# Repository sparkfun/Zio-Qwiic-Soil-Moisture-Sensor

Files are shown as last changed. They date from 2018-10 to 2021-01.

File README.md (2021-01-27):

SparkFun Qwiic Soil Moisture Sensor
========================================

SparkFun Qwiic Soil Moisture Sensor

[*SparkFun Qwiic Soil Moisture Sensor (17731)*](https://www.sparkfun.com/products/17731)

The SparkFun Qwiic Soil Moisture Sensor is a simple breakout for measuring the moisture in soil and similar materials. The soil moisture sensor is pretty straightforward to use. The two large, exposed pads function as probes for the sensor, together acting as a variable resistor. The more water that is in the soil means the better the conductivity between the pads will be, resulting in a lower resistance and a higher SIG out. This version of the Soil Moisture Sensor includes a Qwiic connector, making it even easier to use this sensor!

To get the SparkFun Soil Moisture Sensor functioning, all you will need is to connect the VCC and GND pins to your Arduino-based device (or compatible development board). You will receive a SIG out, which will depend on the amount of water in the soil. One commonly known issue with soil moisture senors is their short lifespan when exposed to a moist environment. To combat this, we’ve had the PCB coated in gold finishing (ENIG, or Electroless Nickel Immersion Gold).

Built in cooperation with [Zio Smart Prototyping](https://www.smart-prototyping.com/Zio/Zio-Qwiic-Soil-Moisture-Sensor)! 

#### Specification

* I2C address: 0x07- 0x78 (Default: 0x28)
* Gateway MCU: ATtiny85-20SU
* Probes Surface Finish: Gold Immersion
* Weight: 6.0g
* Module dimension: 20.3x 100.0mm

Documentation
--------------
* **[Hookup Guide](https://learn.sparkfun.com/tutorials/soil-moisture-sensor-hookup-guide)** - Basic hookup guide for the SparkFun Qwiic Soil Moisture Sensor.
* [ATtiny85 Gateway Firmware](https://github.com/ZIOCC/Zio-Qwiic-Soil-Moisture-Sensor/tree/master/Firmware/Qwiic_Soil_Moisture_Sensor_Gateway_Firmware/Qwiic_Soil_Moisture_Firmware)

License Information
-------------------

This product is _**open source**_! 

Please review the LICENSE.md file for license information. 

If you have any questions or concerns on licensing, please contact technical support on our [SparkFun forums](https://forum.sparkfun.com/viewforum.php?f=152).

Distributed as-is; no warranty is given.

- Your friends at SparkFun.

_<COLLABORATION CREDIT>_

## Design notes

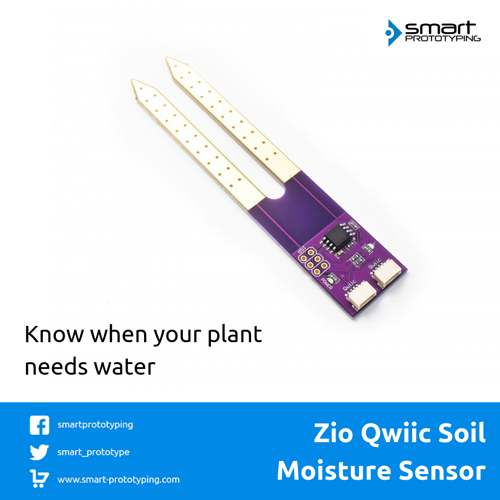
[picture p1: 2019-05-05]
soil-moisture.png

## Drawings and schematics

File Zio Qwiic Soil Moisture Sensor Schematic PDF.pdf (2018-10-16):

1 | 2 | 3 | 4

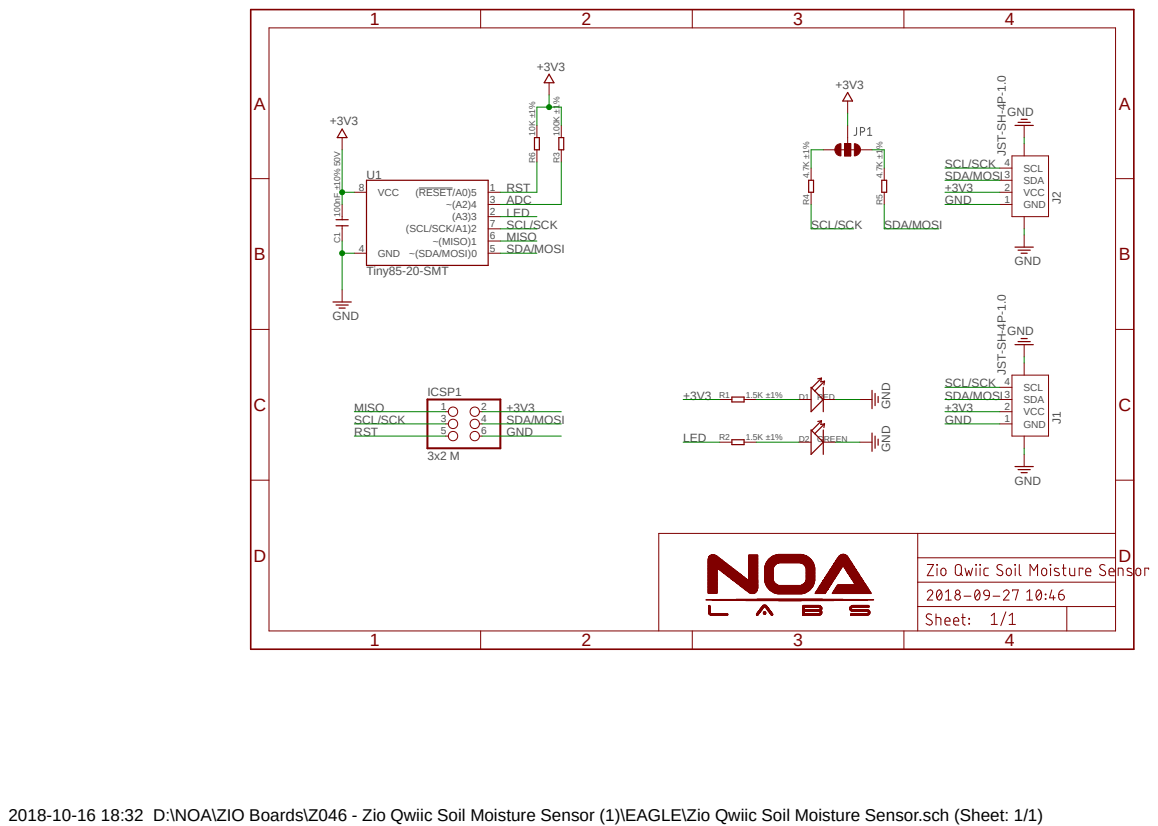
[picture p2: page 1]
Tiny85-20-SMT; GND¹⁰⁰nF ±10% ⁵⁰V; GND; GND 4.7K ±1%; RED; GREEN; GND GND ¹⁰⁰K ±1%; GND ¹⁰K ±1%; U1 VCC 8; ~(MISO)1; (RESET/A0)5; GND 4; ~(SDA/MOSI)0; (SCL/SCK/A1)2; GND 1; VCC 2; SDA 3; SCL 4; J2 JST⁻SH⁻⁴P⁻¹.0 R⁴; ICSP1 1 2 3 4 5 6; J1 JST⁻SH⁻⁴P⁻¹.0 R⁶; LED; ADC; RST; SDA/MOSI; SCL/SCK; MISO

2018-10-16 18:32 D:\NOA\ZIO Boards\Z046 - Zio Qwiic Soil Moisture Sensor (1)\EAGLE\Zio Qwiic Soil Moisture Sensor.sch (Sheet: 1/1)

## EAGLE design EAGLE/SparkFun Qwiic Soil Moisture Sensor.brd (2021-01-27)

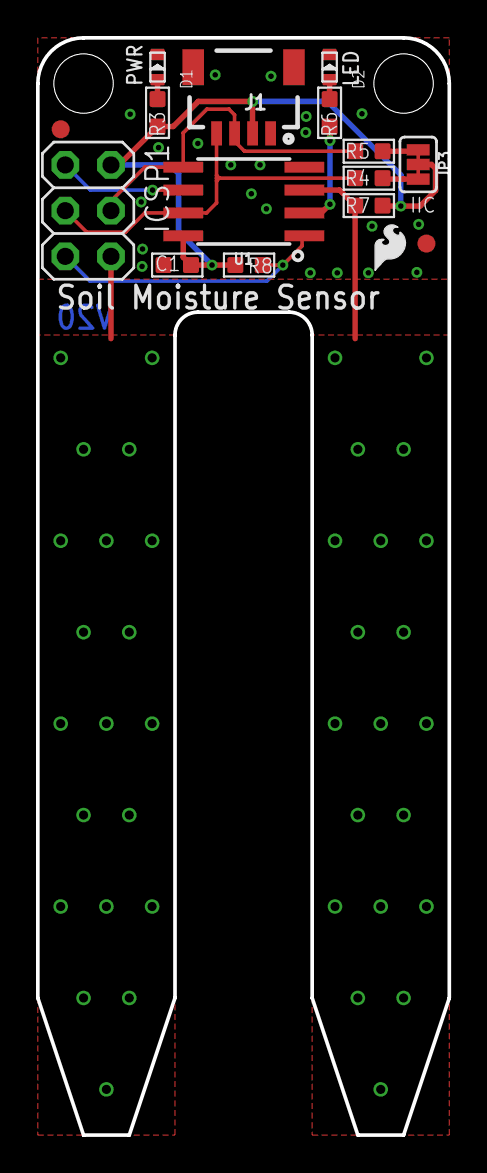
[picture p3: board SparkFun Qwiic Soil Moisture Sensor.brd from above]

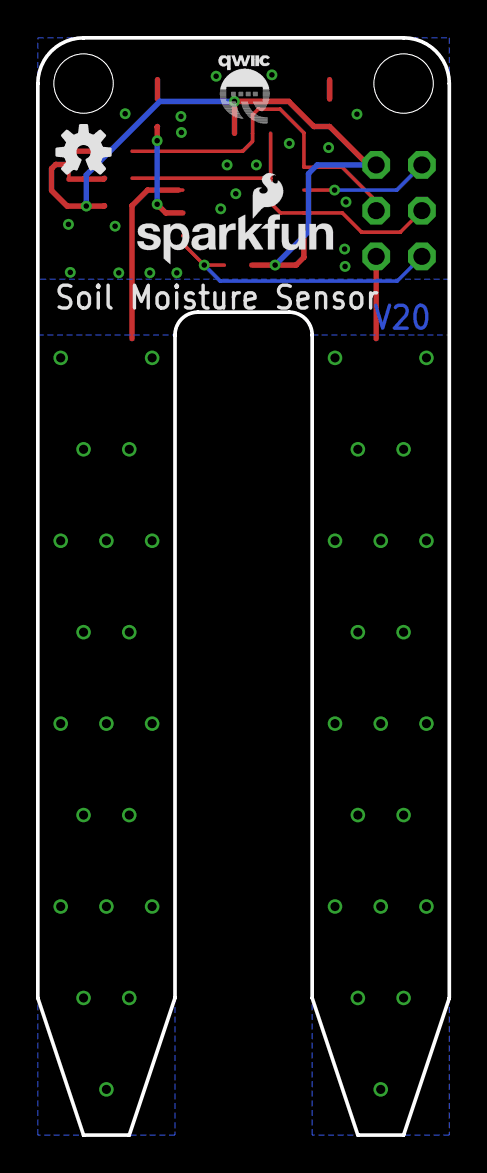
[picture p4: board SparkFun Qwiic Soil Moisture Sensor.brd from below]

Board: 2 copper layers, 22.9 x 61.0 mm, 21 parts (3 on the bottom side), 12 nets.

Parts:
C1: 100nF ±10% 50V; C0603
D1: RED; LED-0603
D2: GREEN; LED-0603
FID1, FID2: FIDUCIAL1X2; FIDUCIAL-1X2
ICSP1: 3x2 M; 2X03
J1: JST-SH-4P-1.0; JST-SH-4P
JP3: SMT-JUMPER_3_2-NC_TRACE
LOGO1: SFE_LOGO_NAME_FLAME.1_INCH; SFE_LOGO_NAME_FLAME_.1
LOGO2: OSHW-LOGOS; OSHW-LOGO-S
R3, R6: 1.5K ±1%; R0603
R4, R5: 4.7K ±1%; R0603
R7: 100K ±1%; R0603
R8: 10K ±1%; R0603
STANDOFF1, STANDOFF2: STAND-OFF
U1: Tiny85-20-SMT; SO08-EIAJ_MCU
U$2: SFE_LOGO_FLAME_.1
U$5: QWIIC-LOGO-SMALL

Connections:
+3V3: C1.2, ICSP1.2, J1.2, JP3.2, R3.1, R7.2, R8.2, U1.8
ADC: R7.1, U1.3
GND: C1.1, D1.-, D2.-, ICSP1.6, J1.1, J1.NC1, J1.NC2, U1.4
LED: R6.1, U1.2
MISO: ICSP1.1, U1.6
unnamed: D1.+, R3.2
unnamed: D2.+, R6.2
unnamed: JP3.3, R4.2
unnamed: JP3.1, R5.2
RST: ICSP1.5, R8.1, U1.1
SCL/SCK: ICSP1.3, J1.4, R4.1, U1.7
SDA/MOSI: ICSP1.4, J1.3, R5.1, U1.5

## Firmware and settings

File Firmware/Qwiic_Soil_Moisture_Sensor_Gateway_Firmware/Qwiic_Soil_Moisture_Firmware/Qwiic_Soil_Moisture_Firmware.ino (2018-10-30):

/******************************************************************************
  Zio Qwiic Soil Moisture Sensor Firmware
  Harry
  September 25, 2018

  This is the firmware on the Zio Qwiic Soil Moisture Sensor. The default I2C Address is
  0x28;

******************************************************************************/
#include <TinyWire.h> //https://github.com/lucullusTheOnly/TinyWire
#include <EEPROM.h>

#define LED_PIN   3
#define ADC_PIN   A2
#define SETTING_LOCATION_ADDRESS	1

volatile byte qwiicAddress  =    0x28; //default

#define COMMAND_LED_OFF 			0x00
#define COMMAND_LED_ON 			0x01
#define COMMAND_CHANGE_ADDRESS 		0x03
#define COMMAND_GET_VALUE 				0x05
#define COMMAND_HAS_BEEN_CHECKED 	0x99

volatile byte command = COMMAND_HAS_BEEN_CHECKED;
volatile byte address = COMMAND_HAS_BEEN_CHECKED;
uint16_t ADC_VALUE=0;
uint8_t  ADC_VALUE_H=0,ADC_VALUE_L=0;

void setup() {
  //Read EEPROM, is it empty (0xFF)? or does it have a value?
  qwiicAddress =  EEPROM.read(SETTING_LOCATION_ADDRESS);
  if (qwiicAddress == 0xFF) {
    //EEPROM has never been written before, use the default address 0x28.
    qwiicAddress = 0x28; //default
  }

  TinyWire.begin(qwiicAddress);
  TinyWire.onReceive(receiveEvent); // register event
  TinyWire.onRequest(onI2CRequest);
}

void loop() {
}

/*========================================================*/
//        ISR
/*========================================================*/

// When the master initiates a command and data to slave
//		ie) the master says 0x01, then sends a 1, means command: 0x01 then the slave listens for the next thing, which is the LED state 1
void receiveEvent(int bytesReceived) {
  byte count = 0;
  while (TinyWire.available() > 0) {
    if (count == 0) {
      command = TinyWire.read();

      if (command == COMMAND_LED_ON) {
        digitalWrite(LED_PIN, HIGH);
        command = COMMAND_HAS_BEEN_CHECKED;
      }
      else if (command == COMMAND_LED_OFF) {
        digitalWrite(LED_PIN, LOW);
        command = COMMAND_HAS_BEEN_CHECKED;
      }
    }
    else if (count == 1) {
      if (command == COMMAND_CHANGE_ADDRESS) {
        byte address = TinyWire.read();

        if (address > 0x07 && address < 0x78) {
          //valid address, update and save to EEPROM
          qwiicAddress = address;

          EEPROM.write(SETTING_LOCATION_ADDRESS, qwiicAddress);
          TinyWire.begin(qwiicAddress);
        }
      }
    }
    else {
      TinyWire.read(); //read the data coming in but ignore it.
    }
    count++;
  }
}// end of receive ISR

//When the master requests data from the slave, this
//    ISR is triggered.

void onI2CRequest() {
   if (command == COMMAND_GET_VALUE) {
    ADC_VALUE=analogRead(ADC_PIN);
    ADC_VALUE_L=ADC_VALUE;
    ADC_VALUE_H=ADC_VALUE>>8; 
    TinyWire.send(ADC_VALUE_L);  
    TinyWire.send(ADC_VALUE_H);
    command = COMMAND_HAS_BEEN_CHECKED;
  }
}

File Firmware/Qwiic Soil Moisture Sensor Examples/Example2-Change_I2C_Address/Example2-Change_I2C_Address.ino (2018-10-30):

/******************************************************************************
  Zio Qwiic Soil Moisture Sensor Example 2 - base Reading
  Harry
  September 25, 2018

  This sketch demonstrates how to change the I2C Address
  of the Zio Qwiic Soil Moisture Sensor. The new address will be saved to the
  Sensor's EEPROM.

  The factory default slave address is 0x28.

  Note: If the Zio Qwiic Soil Moisture Sensor is connected but unresponsive, 
  try Example 3 - I2C_Scanner to find the current address of the Sensor.

  Only valid address can be saved to the Sensor's EEPROM. If an invalid address is
  sent, the Sensor will ignore the address change without notifying the user.

******************************************************************************/
#include <Wire.h>
#define COMMAND_LED_OFF 				  0x00
#define COMMAND_LED_ON 				    0x01
#define COMMAND_CHANGE_ADDRESS 			0x03

volatile byte qwiicAddress = 0x28;     //Default Address

void setup() {
  Serial.begin(9600);
  Serial.println("Zio Qwiic Soil Moisture Sensor Master Awake");
  Wire.begin(); // join the I2C Bus

  Wire.beginTransmission(qwiicAddress); // transmit to device
  //check here for an ACK from the slave
  if (Wire.endTransmission() != 0 ) {
    Serial.println("Check Connections. Slave not found.");
  }

  Serial.println("Zio Qwiic Soil Moisture Sensor found!");

  ledOn(); // Turn on the LED (at address 0x28)
  delay(1000);
  byte error = changeAddress(0x29); // Change the Sensor's address to 0x29
  ledOff(); // Turn off the LED (at address 0x29)
  delay(1000);
  changeAddress(0x00); // Try to change address to Invalid Address.

  if (error != true) {
    Serial.println("!!!!! invalid address" );
  }
  Serial.println("success");
}

void loop() {
}
// changeAddress() takes a 7 bit I2C Address
// and writes it to the Sensor. This function
// checks to see if the address is between
// 0x07 and 0x78. If valid, the new address is
// saved to the Sensor's EEPROM. If not valid
// address is not changed and is ignored.
// This function returns true if successful and
// false if unsuccessful.
boolean changeAddress(byte address) {
  Wire.beginTransmission(qwiicAddress);
  //check here for an ACK from the slave
  if (Wire.endTransmission()  != 0) {
    Serial.println("Check Connections. No slave found.");
    return (false);
  }

  //check if valid address.
  if (address < 0x07 || address > 0x78) {
    Serial.println("Invalid I2C address");
    return (false);
  }
  //valid address
  Wire.beginTransmission(qwiicAddress);
  Wire.write(COMMAND_CHANGE_ADDRESS);
  qwiicAddress = address;
  Wire.write(qwiicAddress);
  Wire.endTransmission();
  return (true); //Success!
}

// ledOn() turns on the relay at the SLAVE_ADDRESS
// Checks to see if a slave is connected and prints a
// message to the Serial Monitor if no slave found.
void ledOn() {
  Wire.beginTransmission(qwiicAddress);
  Wire.write(COMMAND_LED_ON);
  Wire.endTransmission();
}

// ledOff() turns off the relay at the SLAVE_ADDRESS
// Checks to see if a slave is connected and prints a
// message to the Serial Monitor if no slave found.
void ledOff() {
  Wire.beginTransmission(qwiicAddress);
  Wire.write(COMMAND_LED_OFF);
  Wire.endTransmission();
}

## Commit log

2021-01-27 Updating Board File. Schematic to come
    Updating Board File. Waiting on Schematic.
    [SparkFun Soil Moisture Sensor.brd, Zio Qwiic Soil Moisture Sensor.brd]
2021-01-27 Updating brd and sch to match
    [SparkFun Qwiic Soil Moisture Sensor.brd, SparkFun Qwiic Soil Moisture Sensor.sch]
2021-01-28 Update SparkFun Qwiic Soil Moisture Sensor.sch
    [SparkFun Qwiic Soil Moisture Sensor.sch]

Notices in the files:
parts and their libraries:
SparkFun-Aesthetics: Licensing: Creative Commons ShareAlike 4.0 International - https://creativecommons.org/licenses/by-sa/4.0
